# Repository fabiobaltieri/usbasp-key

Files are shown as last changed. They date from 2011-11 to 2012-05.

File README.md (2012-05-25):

USBASP KEY
==========

http://fabiobaltieri.com/2011/09/02/usb-key-avr-programmer/

This project is an AVR ISP programmer with USB interface in a compact usb
key PCB. The project is based on the original USBasp version of Thomas Fischl,
which can be found on:

http://www.fischl.de/usbasp/

License
-------

This program is free software: you can redistribute it and/or modify
it under the terms of the GNU General Public License as published by
the Free Software Foundation, either version 2 of the License, or
(at your option) any later version.

Contents
--------

    COPYING     text version of the GPL
    README      this file
    binaries/   pre-built firmware images in hex format
    firmware/   source directory for firmware files
    hardware/   source directory for the hardware design files

Firmware
--------

Building requires an avr-gcc toolchain, in the firmware/ directory, to build
run:

    make main.hex

Flashing the firmware on the device requires avrdude and a compatible hardware
programmer. Default configuration is stored at the beginning of the Makefile.
To program with the default configuration, run:

    make flash

Fuses can be configured running:

    make fuses

Hardware
--------

All hardware files (schematic, layout and libraries) are in CadSoft Eagle
format.

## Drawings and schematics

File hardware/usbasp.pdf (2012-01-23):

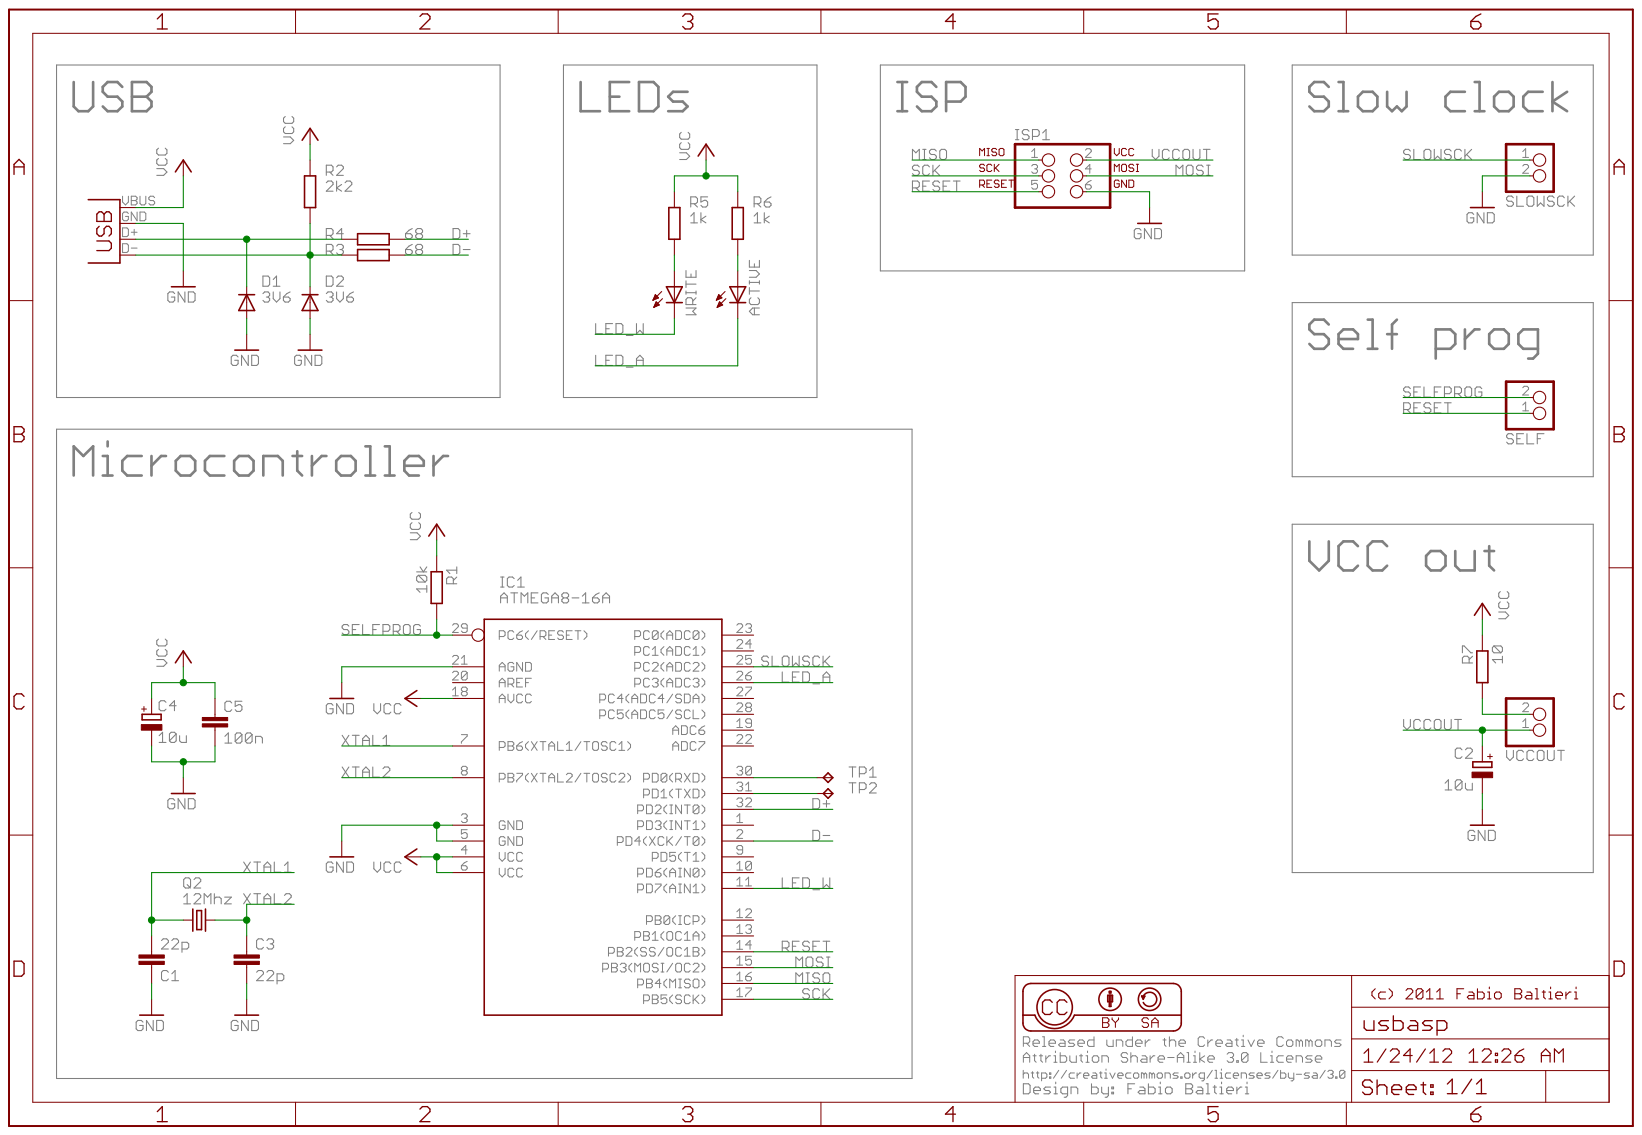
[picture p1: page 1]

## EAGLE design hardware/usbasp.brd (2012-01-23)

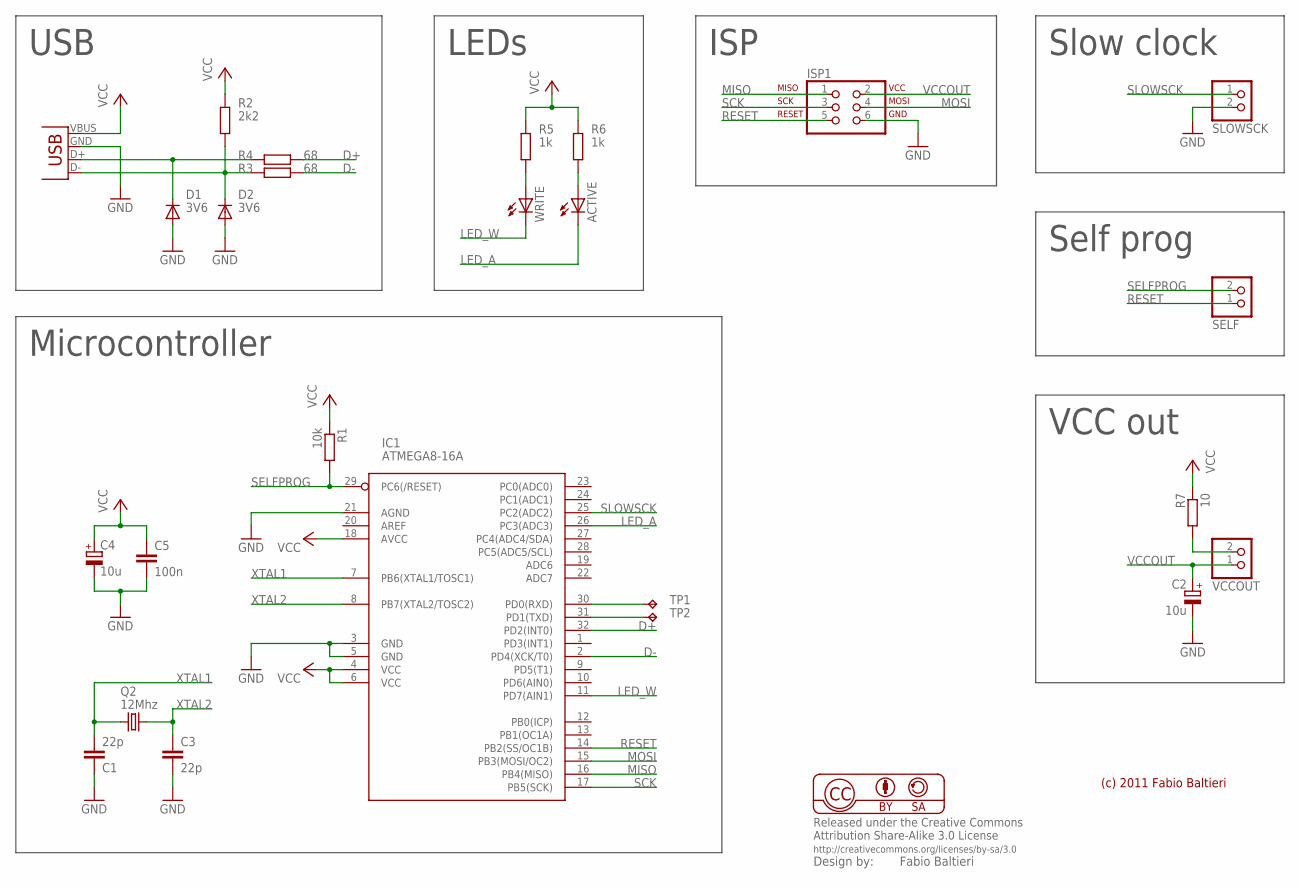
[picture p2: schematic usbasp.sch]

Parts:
ACTIVE: LEDCHIP-LED0805; CHIP-LED0805
C1, C3: 22p; C0805
C2, C4: 10u; SMC_A
C5: 100n; C0805
D1, D2: 3V6; SMA-DIODE
IC1: ATMEGA8-16A; TQFP32-08
ISP1: ISP-AVR910SMD; 2X03_BORDER
Q2: 12Mhz; HC49US
R1: 10k; M0805
R2: 2k2; M0805
R3, R4: 68; M0805
R5, R6: 1k; M0805
R7: 10; M0805
SELF: PINHD-1X2; 1X02
SLOWSCK: PINHD-1X2; 1X02
TP1, TP2: TPB1,27; B1,27
VCCOUT: PINHD-1X2; 1X02
WRITE: LEDCHIP-LED0805; CHIP-LED0805
X1: USB-A-H

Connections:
D+: IC1.32 (PD2(INT0)), R4.1
D-: IC1.2 (PD4(XCK/T0)), R3.1
GND: C1.1, C2.-, C3.1, C4.-, C5.2, D1.A, D2.A, IC1.3 (GND), IC1.5 (GND), IC1.21 (AGND), ISP1.6, SLOWSCK.2, X1.GND (VBUS)
LED_A: ACTIVE.C, IC1.26 (PC3(ADC3))
LED_W: IC1.11 (PD7(AIN1)), WRITE.C
MISO: IC1.16 (PB4(MISO)), ISP1.1
MOSI: IC1.15 (PB3(MOSI/OC2)), ISP1.4
unnamed: R5.2, WRITE.A
unnamed: D1.C, R4.2, X1.D+ (D-)
unnamed: D2.C, R2.1, R3.2, X1.D- (D+)
unnamed: ACTIVE.A, R6.2
unnamed: IC1.30 (PD0(RXD)), TP1.TP
unnamed: R7.2, VCCOUT.2
unnamed: IC1.31 (PD1(TXD)), TP2.TP
RESET: IC1.14 (PB2(SS/OC1B)), ISP1.5, SELF.1
SCK: IC1.17 (PB5(SCK)), ISP1.3
SELFPROG: IC1.29 (PC6(/RESET)), R1.2, SELF.2
SLOWSCK: IC1.25 (PC2(ADC2)), SLOWSCK.1
VCC: C4.+, C5.1, IC1.4 (VCC), IC1.6 (VCC), IC1.18 (AVCC), R1.1, R2.2, R5.1, R6.1, R7.1, X1.VBUS (GND)
VCCOUT: C2.+, ISP1.2, VCCOUT.1
XTAL1: C1.2, IC1.7 (PB6(XTAL1/TOSC1)), Q2.2
XTAL2: C3.2, IC1.8 (PB7(XTAL2/TOSC2)), Q2.1

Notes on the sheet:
(c) 2011 Fabio Baltieri
Microcontroller
USB
LEDs
ISP
Slow clock
Self prog
VCC out

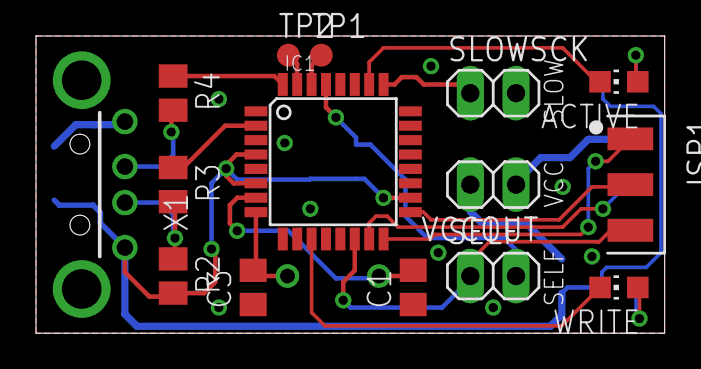
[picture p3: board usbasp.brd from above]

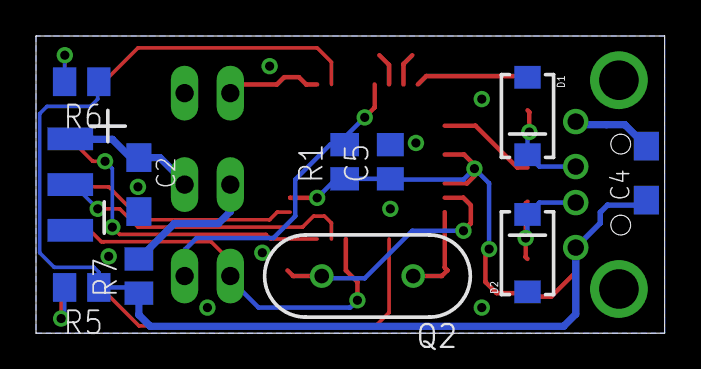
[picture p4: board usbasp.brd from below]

Board: 2 copper layers, 34.9 x 16.5 mm, 25 parts (10 on the bottom side), 22 nets.

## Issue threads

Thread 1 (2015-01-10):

Firmware issue

4eef, 2015-01-10:
Hello!
At the moment I need a linker which can link the hex via TPI interface used in ATtiny10. I have a FT232 linker but it cannot provide link via TPI (I'm using Windows). So I decided to make a USBasp linker, because it works fine with avrdude and has a TPI support with last firmware version.
Today I made your version of USBasp, using your PCB. I noticed that you've been used an old firmware version, which actually does not support linking via TPI interface. Have you updated your FW version to actual (2011-05-28)? Or, if not, please tell me, which things exactly was changed in your FW. I'll try to do changes to new FW myself.

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

fabiobaltieri, 2015-01-16:
Hi! Yeah I never needed to use TPI so I never upgraded the base firmware to include support for that. It should be easy to port the latest release to the hardware since I started this branch from the plain 2009-10-23 firmware. The diff from the base commit is a bit messed up since there is a file conversion in the middle but it should be sufficient to reproduce this commits (the first 4 should be enough):

https://github.com/fabiobaltieri/usbasp-key/commit/e1b1b2193f1e0a9cb3c87c01657b12d8a2afb0b5
https://github.com/fabiobaltieri/usbasp-key/commit/d85b59fdc568937bbcd14ee972ed80d06a309ad8
https://github.com/fabiobaltieri/usbasp-key/commit/e5ba3d4779f53f2150b88546335cf4c19aaf9142
https://github.com/fabiobaltieri/usbasp-key/commit/46f3b817152c2837b01e39f571859f09a2612b5c
https://github.com/fabiobaltieri/usbasp-key/commit/1d6f70df7eaaf18ad91d8f58d7f3d3a0c65d8a11
https://github.com/fabiobaltieri/usbasp-key/commit/f61f34c66c5a9f1bc2096f2d5ab2d9d69f788adf

Nice prototype!

4eef, 2015-01-16:
Thanks a lot! There also needed pin remap for USB (see file usbconfig.h).
I've already compiled and programmed my own one and used it for linking the program to ATtiny10. Seems to be working perfect.
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
I've attached an archive with latest firmware version (2011-05-28) for your PCB in case of it need by anyone.
http://rghost.ru/60385505

fabiobaltieri, 2015-01-16:
Sweet, thanks for sharing! Hey got some fabbing/assembly skill here! That looks *very* nice and clean, especially since you don't have the solder mask and vias plating! Also really cool twisting on the cable! :-)

Closed 2015-01-16.

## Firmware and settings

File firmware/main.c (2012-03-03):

/*
 * Copyright 2011 Fabio Baltieri (fabio.baltieri@gmail.com)
 *
 * Based on the original USBasp code written by
 *   Thomas Fischl <tfischl@gmx.de>, Copyright 2005
 *
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
 */

#include <avr/io.h>
#include <avr/interrupt.h>
#include <avr/pgmspace.h>
#include <avr/wdt.h>
#include <util/delay.h>

#include "usbasp.h"
#include "usbdrv.h"
#include "isp.h"
#include "clock.h"

static uchar replyBuffer[8];

static uchar prog_state = PROG_STATE_IDLE;
static uchar prog_sck = USBASP_ISP_SCK_AUTO;

static uchar prog_address_newmode = 0;
static unsigned long prog_address;
static unsigned int prog_nbytes = 0;
static unsigned int prog_pagesize;
static uchar prog_blockflags;
static uchar prog_pagecounter;

uchar usbFunctionSetup(uchar data[8]) {

	uchar len = 0;

	if (data[1] == USBASP_FUNC_CONNECT) {

		/* set SCK speed */
		if ((PINC & (1 << PC2)) == 0) {
			ispSetSCKOption(USBASP_ISP_SCK_8);
		} else {
			ispSetSCKOption(prog_sck);
		}

		/* set compatibility mode of address delivering */
		prog_address_newmode = 0;

		ledRedOn();
		ispConnect();

	} else if (data[1] == USBASP_FUNC_DISCONNECT) {
		ispDisconnect();
		ledRedOff();

	} else if (data[1] == USBASP_FUNC_TRANSMIT) {
		replyBuffer[0] = ispTransmit(data[2]);
		replyBuffer[1] = ispTransmit(data[3]);
		replyBuffer[2] = ispTransmit(data[4]);
		replyBuffer[3] = ispTransmit(data[5]);
		len = 4;

	} else if (data[1] == USBASP_FUNC_READFLASH) {

		if (!prog_address_newmode)
			prog_address = (data[3] << 8) | data[2];

		prog_nbytes = (data[7] << 8) | data[6];
		prog_state = PROG_STATE_READFLASH;
		len = 0xff; /* multiple in */

	} else if (data[1] == USBASP_FUNC_READEEPROM) {

		if (!prog_address_newmode)
			prog_address = (data[3] << 8) | data[2];

		prog_nbytes = (data[7] << 8) | data[6];
		prog_state = PROG_STATE_READEEPROM;
		len = 0xff; /* multiple in */

	} else if (data[1] == USBASP_FUNC_ENABLEPROG) {
		replyBuffer[0] = ispEnterProgrammingMode();
		len = 1;

	} else if (data[1] == USBASP_FUNC_WRITEFLASH) {

		if (!prog_address_newmode)
			prog_address = (data[3] << 8) | data[2];

		prog_pagesize = data[4];
		prog_blockflags = data[5] & 0x0F;
		prog_pagesize += (((unsigned int) data[5] & 0xF0) << 4);
		if (prog_blockflags & PROG_BLOCKFLAG_FIRST) {
			prog_pagecounter = prog_pagesize;
		}
		prog_nbytes = (data[7] << 8) | data[6];
		prog_state = PROG_STATE_WRITEFLASH;
		len = 0xff; /* multiple out */

	} else if (data[1] == USBASP_FUNC_WRITEEEPROM) {

		if (!prog_address_newmode)
			prog_address = (data[3] << 8) | data[2];

		prog_pagesize = 0;
		prog_blockflags = 0;
		prog_nbytes = (data[7] << 8) | data[6];
		prog_state = PROG_STATE_WRITEEEPROM;
		len = 0xff; /* multiple out */

	} else if (data[1] == USBASP_FUNC_SETLONGADDRESS) {

		/* set new mode of address delivering (ignore address delivered in commands) */
		prog_address_newmode = 1;
		/* set new address */
		prog_address = *((unsigned long*) &data[2]);

	} else if (data[1] == USBASP_FUNC_SETISPSCK) {

		/* set sck option */
		prog_sck = data[2];
		replyBuffer[0] = 0;
		len = 1;
	}

	usbMsgPtr = replyBuffer;

	return len;
}

uchar usbFunctionRead(uchar *data, uchar len) {

	uchar i;

	/* check if programmer is in correct read state */
	if ((prog_state != PROG_STATE_READFLASH) && (prog_state
			!= PROG_STATE_READEEPROM)) {
		return 0xff;
	}

	/* fill packet */
	for (i = 0; i < len; i++) {
		if (prog_state == PROG_STATE_READFLASH) {
			data[i] = ispReadFlash(prog_address);
		} else {
			data[i] = ispReadEEPROM(prog_address);
		}
		prog_address++;
	}

	/* last packet? */
	if (len < 8) {
		prog_state = PROG_STATE_IDLE;
	}

	return len;
}

uchar usbFunctionWrite(uchar *data, uchar len) {

	uchar retVal = 0;
	uchar i;

	/* check if programmer is in correct write state */
	if ((prog_state != PROG_STATE_WRITEFLASH) && (prog_state
			!= PROG_STATE_WRITEEEPROM)) {
		return 0xff;
	}

	for (i = 0; i < len; i++) {

		if (prog_state == PROG_STATE_WRITEFLASH) {
			/* Flash */

			if (prog_pagesize == 0) {
				/* not paged */
				ispWriteFlash(prog_address, data[i], 1);
			} else {
				/* paged */
				ispWriteFlash(prog_address, data[i], 0);
				prog_pagecounter--;
				if (prog_pagecounter == 0) {
					ispFlushPage(prog_address, data[i]);
					prog_pagecounter = prog_pagesize;
				}
			}

		} else {
			/* EEPROM */
			ispWriteEEPROM(prog_address, data[i]);
		}

		prog_nbytes--;

		if (prog_nbytes == 0) {
			prog_state = PROG_STATE_IDLE;
			if ((prog_blockflags & PROG_BLOCKFLAG_LAST) && (prog_pagecounter
					!= prog_pagesize)) {

				/* last block and page flush pending, so flush it now */
				ispFlushPage(prog_address, data[i]);
			}

			retVal = 1; // Need to return 1 when no more data is to be received
		}

		prog_address++;
	}

	return retVal;
}

int main(void) {
	uchar i;

	/* no pullups on USB and ISP pins */
	PORTD = _BV(PD7);
	PORTB = 0;
	PORTC = _BV(PC2) | _BV(PC3);
	DDRD |= _BV(PD7);
	DDRC |= _BV(PC3);

	usbInit();
	usbDeviceDisconnect();

	for (i = 0; i < 5; i++) {
		ledGreenOff();
		_delay_ms(50);
		ledGreenOn();
		_delay_ms(50);
	}

	/* init timer */
	clockInit();

	usbDeviceConnect();

	/* main event loop */
	sei();
	for (;;) {
		usbPoll();
	}
	return 0;
}

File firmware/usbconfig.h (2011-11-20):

/*
 * Copyright 2011 Fabio Baltieri (fabio.baltieri@gmail.com)
 *
 * Based on the original USBasp code written by
 *   Christian Starkjohann, Copyright 2005, OBJECTIVE DEVELOPMENT Software GmbH
 *   Thomas Fischl <tfischl@gmx.de>, Copyright 2005
 *
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
 */

#ifndef __usbconfig_h_included__
#define __usbconfig_h_included__

/*
General Description:
This file contains parts of the USB driver which can be configured and can or
must be adapted to your hardware.

Please note that the usbdrv contains a usbconfig-prototype.h file now. We
recommend that you use that file as a template because it will always list
the newest features and options.
*/

/* ---------------------------- Hardware Config ---------------------------- */

#define USB_CFG_IOPORTNAME      D
/* This is the port where the USB bus is connected. When you configure it to
 * "B", the registers PORTB, PINB and DDRB will be used.
 */
#define USB_CFG_DMINUS_BIT      4
/* This is the bit number in USB_CFG_IOPORT where the USB D- line is connected.
 * This may be any bit in the port.
 */
#define USB_CFG_DPLUS_BIT       2
/* This is the bit number in USB_CFG_IOPORT where the USB D+ line is connected.
 * This may be any bit in the port. Please note that D+ must also be connected
 * to interrupt pin INT0!
 */
#define USB_CFG_CLOCK_KHZ       (F_CPU/1000)
/* Clock rate of the AVR in MHz. Legal values are 12000, 16000 or 16500.
 * The 16.5 MHz version of the code requires no crystal, it tolerates +/- 1%
 * deviation from the nominal frequency. All other rates require a precision
 * of 2000 ppm and thus a crystal!
 * Default if not specified: 12 MHz
 */

/* ----------------------- Optional Hardware Config ------------------------ */

/* #define USB_CFG_PULLUP_IOPORTNAME   D */
/* If you connect the 1.5k pullup resistor from D- to a port pin instead of
 * V+, you can connect and disconnect the device from firmware by calling
 * the macros usbDeviceConnect() and usbDeviceDisconnect() (see usbdrv.h).
 * This constant defines the port on which the pullup resistor is connected.
 */
/* #define USB_CFG_PULLUP_BIT          4 */
/* This constant defines the bit number in USB_CFG_PULLUP_IOPORT (defined
 * above) where the 1.5k pullup resistor is connected. See description
 * above for details.
 */

/* --------------------------- Functional Range ---------------------------- */

#define USB_CFG_HAVE_INTRIN_ENDPOINT    0
/* Define this to 1 if you want to compile a version with two endpoints: The
 * default control endpoint 0 and an interrupt-in endpoint 1.
 */
#define USB_CFG_HAVE_INTRIN_ENDPOINT3   0
/* Define this to 1 if you want to compile a version with three endpoints: The
 * default control endpoint 0, an interrupt-in endpoint 1 and an interrupt-in
 * endpoint 3. You must also enable endpoint 1 above.
 */
#define USB_CFG_IMPLEMENT_HALT          0
/* Define this to 1 if you also want to implement the ENDPOINT_HALT feature
 * for endpoint 1 (interrupt endpoint). Although you may not need this feature,
 * it is required by the standard. We have made it a config option because it
 * bloats the code considerably.
 */
#define USB_CFG_INTR_POLL_INTERVAL      10
/* If you compile a version with endpoint 1 (interrupt-in), this is the poll
 * interval. The value is in milliseconds and must not be less than 10 ms for
 * low speed devices.
 */
#define USB_CFG_IS_SELF_POWERED         0
/* Define this to 1 if the device has its own power supply. Set it to 0 if the
 * device is powered from the USB bus.
 */
#define USB_CFG_MAX_BUS_POWER           50
/* Set this variable to the maximum USB bus power consumption of your device.
 * The value is in milliamperes. [It will be divided by two since USB
 * communicates power requirements in units of 2 mA.]
 */
#define USB_CFG_IMPLEMENT_FN_WRITE      1
/* Set this to 1 if you want usbFunctionWrite() to be called for control-out
 * transfers. Set it to 0 if you don't need it and want to save a couple of
 * bytes.
 */
#define USB_CFG_IMPLEMENT_FN_READ       1
/* Set this to 1 if you need to send control replies which are generated
 * "on the fly" when usbFunctionRead() is called. If you only want to send
 * data from a static buffer, set it to 0 and return the data from
 * usbFunctionSetup(). This saves a couple of bytes.
 */
#define USB_CFG_IMPLEMENT_FN_WRITEOUT   0
/* Define this to 1 if you want to use interrupt-out (or bulk out) endpoint 1.
 * You must implement the function usbFunctionWriteOut() which receives all
 * interrupt/bulk data sent to endpoint 1.
 */
#define USB_CFG_HAVE_FLOWCONTROL        0
/* Define this to 1 if you want flowcontrol over USB data. See the definition
 * of the macros usbDisableAllRequests() and usbEnableAllRequests() in
 * usbdrv.h.
 */

/* -------------------------- Device Description --------------------------- */
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

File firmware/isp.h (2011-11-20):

/*
 * Copyright 2011 Fabio Baltieri (fabio.baltieri@gmail.com)
 *
 * Based on the original USBasp code written by
 *   Thomas Fischl <tfischl@gmx.de>, Copyright 2005
 *
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
 */

#ifndef __isp_h_included__
#define	__isp_h_included__

#ifndef uchar
#define	uchar	unsigned char
#endif

#define	ISP_OUT   PORTB
#define ISP_IN    PINB
#define ISP_DDR   DDRB
#define ISP_RST   PB2
#define ISP_MOSI  PB3
#define ISP_MISO  PB4
#define ISP_SCK   PB5

/* Prepare connection to target device */
void ispConnect();

/* Close connection to target device */
void ispDisconnect();

/* read an write a byte from isp using software (slow) */
uchar ispTransmit_sw(uchar send_byte);

/* read an write a byte from isp using hardware (fast) */
uchar ispTransmit_hw(uchar send_byte);

/* enter programming mode */
uchar ispEnterProgrammingMode();

/* read byte from eeprom at given address */
uchar ispReadEEPROM(unsigned int address);

/* write byte to flash at given address */
uchar ispWriteFlash(unsigned long address, uchar data, uchar pollmode);

uchar ispFlushPage(unsigned long address, uchar pollvalue);

/* read byte from flash at given address */
uchar ispReadFlash(unsigned long address);

/* write byte to eeprom at given address */
uchar ispWriteEEPROM(unsigned int address, uchar data);

/* pointer to sw or hw transmit function */
uchar (*ispTransmit)(uchar);

/* set SCK speed. call before ispConnect! */
void ispSetSCKOption(uchar sckoption);

#endif /* __isp_h_included__ */

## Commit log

2011-08-20 firmware: initial import of original usbasp 2009-10-23 firmware
    This is an import of the original firmware found on:
    http://www.fischl.de/usbasp/
2011-08-20 hardware: imported hardware files
    [usbasp.brd, usbasp.sch]
2011-08-20 hardware: added copyright text
    [usbasp.brd, usbasp.sch]
2011-09-05 hardware: added schematics in pdf version
2011-11-20 hardware: add CC BY-SA license
    [usbasp.brd, usbasp.sch]
2012-01-23 hardware: convert files to eagle v6 format (xml)
    [usbasp.brd, usbasp.sch]
2012-01-23 hardware: coscmetic fixes
    [usbasp.brd, usbasp.sch]
2012-03-03 bootloader: Makefile: set fuse for ATmega168
2012-03-03 bootloader: setup for ATmega168 on usbasp board
2012-03-03 main: change init sequence for correct usb reset
    [main.c]
2012-03-03 main: blink led on init while waiting

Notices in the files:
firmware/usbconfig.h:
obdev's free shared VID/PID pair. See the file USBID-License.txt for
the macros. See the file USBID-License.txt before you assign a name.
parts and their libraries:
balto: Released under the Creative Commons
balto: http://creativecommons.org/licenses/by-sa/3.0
